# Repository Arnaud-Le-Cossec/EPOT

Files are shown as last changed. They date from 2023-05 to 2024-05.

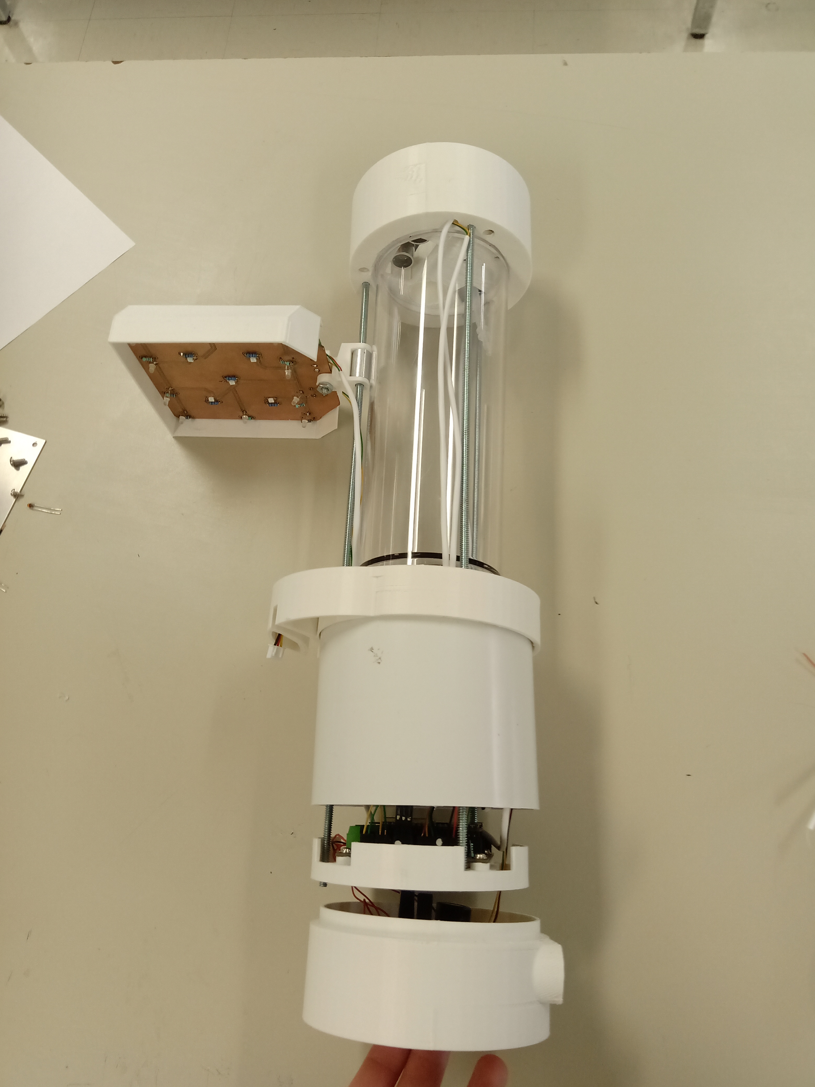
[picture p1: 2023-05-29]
Photo/EPOT_img3.jpg

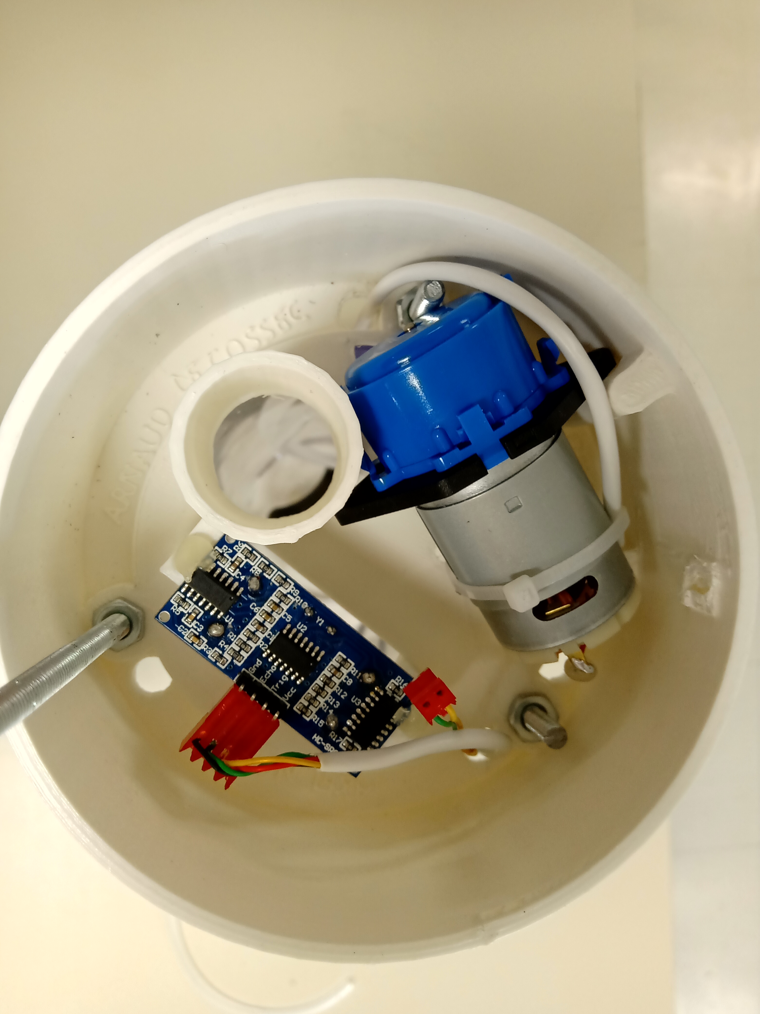
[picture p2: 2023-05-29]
Photo/EPOT_img5.jpg

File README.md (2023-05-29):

# PROJET EPOT

Réalisé par
Arnaud LE COSSEC
Axel NOUY

Session hiver 2023 - Collège Lionel Groulx

Qu'est-ce que EPOT ?

EPOT est un projet réalisé dans le cadre de la session hiver 2023 au collège Lionel Groulx. L'objectif du projet est de permettre à tout le monde faire pousser ses propres plantes chez soi sans avoir la main verte !

Il s'agit d'un pot de fleur intelligent et connecté, contrôlé par une application mobile. EPOT permet d'automatiser l'arrosage et l'éclairage d'une plante grâce à de nombreux capteurs : capteur d'humidité, de luminosité, de température et de niveau d'eau.

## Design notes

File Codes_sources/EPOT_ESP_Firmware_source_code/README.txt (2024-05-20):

READ ME
-------------Comment compiler ce projet ------------
1. ouvrir VScode.
2. Installer PlatformIO.
3. Dans "PlatformIO Home", créer un nouveau projet.
4. Entrer un nom de projet, sélectionner la carte [ESP32 Wrover DevKit] avec Arduino framework.
5. Copier le contenu de "main.cpp" dans le "main" du projet.
6. Copier le fichier "EPOT_lib.h" dans le dossier "src" du project.
7. Dans le fichier "platform.ini", changer ou ajouter les lignes suivantes :
	monitor_speed = 9600
	board_upload.flash_size = 8MB
	board_build.partitions = custom_partition.csv
Le fichier "platform.ini" doit désormais ressembler à celui fourni dans ce dossier
8. Dans la racine du projet, copier le fichier "custom_partition.csv".
9. Depuis "PlatformIO Home", cliquer sur "libraries" pour installer les librairies requises

Le fichier compilé en .elf et .bin est disponible dans le dossier "buid"
----------------- Notes -----------------------
Avant de compiler, il faut changer les paramètres de la base de données dans "EPOT_lib.h" :
#define DATABASE_API_KEY "entrez votre API de base de données"
#define DATABASE_URL "entrez votre URL de base de données" 
#define DATABASE_USER_EMAIL "user@email.com"
#define DATABASE_USER_PASSWORD "PASSWORD123"

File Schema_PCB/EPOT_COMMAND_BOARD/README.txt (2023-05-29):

README
Ce dossier contient l'archive du projet KiCAD du module de commande 
Fichier projet : EPOT_COMMAND_BOARD.kicad_pro
Schéma : EPOT_COMMAND_BOARD.kicad_sch
PCB : EPOT_COMMAND_BOARD.kicad_pcb
Paramètres : EPOT_COMMAND_BOARD.kicad_prl

Vous trouverez également une version .png du schéma ainsi qu'une note indiquant les modifications effectuées sur le circuit imprimé.

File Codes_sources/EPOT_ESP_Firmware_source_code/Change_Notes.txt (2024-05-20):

/*****************************************************
EPOT Project - ESP32 Firmware
(c)2023 Arnaud LE COSSEC
(c)2023 College Lionel Groulx
*****************************************************/

/*****************************************************
Change Notes : 
28/03/2023a : File creation
              void LED_init(void);
              void LED_set(uint8_t freq);
              void Ultrasonic_init(void);
              float Ultrasonic_Read(void);
              void Aref_init(void);
              void Temp_init(void);
              float Temp_Read(void);
              void Photo_Cell_init(void);
              float Photo_Cell_Read(void);
              void Humidity_init(void);
              float Humidity_Read(void);
29/03/2023a : POST test implementation
              LED not flashing bug fixed (prototype used instead of function call)
29/03/2023b : Task implementation
              Task Sensors Update
              Task Sensors Print - debug only, to be removed later on
29/03/2023c : Wifi setup implementation
29/03/2023d : Database setup implementation
              Code separation with EPOT_lib.h
31/03/2023a : watchdog implementation
03/04/2023a : Sensors to database
              Ledc library error fixed
04/04/2023a : Error log to database
              void Database_Self_test_repport(uint8_t Error_Count, uint8_t *Error_log)
              Change uint8_t Self_test(uint8_t *Error_log_table) : text as const char*
04/04/2023b : Bluetooth implementation
12/04/2023a : Startup sequence (stopped due to flash size issue)
13/04/2023a : New partion table with 3MB free for application use
13/04/2023b : Startup sequence (continuation)
              Task_database_read() / Task_database_write() deleted because replaced by task_database_update()
19/04/2023a : Database authentification refresh implementation
              [bug fix] "Invalid data; couldn't parse JSON object, array, or value." fixed : when left unconnected, 
              thermistor value was too large for the database. Temperature capped to 70°C
19/04/2023b : [bug fix] Bluetooth authentification systematic timeout fixed
20/04/2023a : [bug fix] Bluetooth authentification failed when retry
20/04/2023b : SSID and WIFI password exchange
27/04/2023a : Wifi connects from exchanged SSID and Password
27/04/2023b : Queue recieve moved to read sensors more often Task_Database_Update_routine
              Wifi connection timeout : if ESP can't connect to wifi, it restart credidentials exchange via Bluetooth
03/05/2023a : Permanent storage implementation with preferences.h library
              Push button reading implementation
03/05/2023b : Repace sensor queues for global variables to facilitate access for multiple tasks
03/05/2023c : Database commands and threshold levels reading
04/05/2023a : Automation - Force run/stop
              LED GPIO 17 and UV GPIO16 are not connected on VROVER-E. Replaced for GPIO 5 and 15 respectively
08/05/2023a : Database triggers
09/05/2023a : Update commands and levels from database triggers
09/05/2023b : Automation - Auto mode
10/05/2023a : Database sensor update only when sensor value changed
              if button pressed durring operation, hard reset is performed
15/05/2023a : RTOS Removed. RTOS handles memory in a weird way : random crashes due to memory allocation errors. 
15/05/2023b : Database update at startup
18/05/2023a : [BUG FIX] after 1h of runtime, firebase wants to refresh authentification tokens, but fails due to lack of memory
19/05/2023a : Delay added after firebase stream reconnection. Watchdog timeout extended to accomodate this delay.
20/05/2023a : LED to show CPU activity in the loop
22/05/2023a : Added relay output to cut 5v at startup
              Ultrasonic sensor measure overhaul
23/05/2023a : Pump automation overhaul
28/05/2023a : Commenting

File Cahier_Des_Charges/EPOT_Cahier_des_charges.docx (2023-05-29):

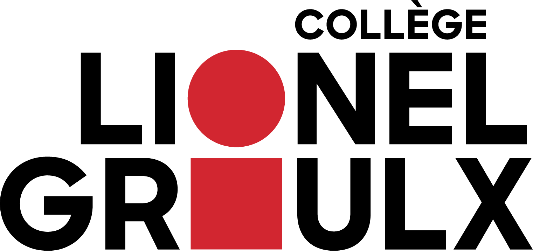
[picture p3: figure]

| | PROJET EPOT
| CAHIER DES CHARGES
Auteurs : Arnaud LE COSSEC Axel NOUY | Date : 27/05/23 | | Révision : v1.0 | Pages : 4

I – AVANT PROPOS

Le présent document revient sur les choix réalisés pour le projet EPOT. Nous reviendrons sur la constitution du cahier des charges puis sur la manière dont il a été mis en place.

II – CAHIER DES CHARGES

Le projet consiste en la création d'un pot de fleur intelligent et connecté, contrôlé par une application mobile. Il devra être capable d'arroser automatiquement les plantes à partir de la mesure de l'humidité du sol. L'éclairage devra lui aussi être contrôlé en fonction de la luminosité extérieure afin d'accomplir la consommation la plus faible possible. Il devra également être capable de mesurer et d'afficher la température dans l'air. L'alimentation devra être connectée au secteur et si possible sur batterie alimenter via un panneau solaire. Tous ces éléments devront être accessibles et contrôlables sur une application mobile. Celle-ci affichera les mesures des différents capteurs et laissera à l'utilisateur le choix d'une opération manuelle ou automatique de l'arrosage et de l'éclairage avec la possibilité de sélectionner des préréglages parmi les plantes proposées (niveau d'humidité, luminosité).

Le tableau ci-dessus récapitule ces exigences :

Fonctionnalités | Ce qui permet de mettre en œuvre ces fonctionnalités | Précision/ Résolution/ Contraintes
Arrosage automatique des plantes | → Capteur humidité du sol → Capteur niveau du réservoir → Électrovanne / Pompe / Brumisateur | Résolution de humidité au pourcentage près. Niveau d’eau au pourcentage près Arrosage lent et précisément contrôlable
Éclairage automatique | → Capteur luminosité ambiante → Lumière réglable (différentes intensités/couleur) → Consommation la plus faible possible | Capteur doit pouvoir traduire les différents niveaux de luminosités de la journée. Éclairage doit pouvoir être supporté par l’alimentation
Surveillance de l'atmosphère | → Capteur de température | Doit donner une idée de la température Résolution au dixième de degré Précision requise faible
Surveillance/gestion sur une application smartphone | → Afficher l'état des capteurs (température niveau d’eau, …) → Réglage sur différents modes (manuel, automatique, type de plante, …) L’utilisateur peut choisir lui-même les niveaux (manuel) ou choisi parmi des préréglages selon le type de plante → Communication des informations via Wi-Fi /Bluetooth | Temps de réaction le plus faible possible
Alimentation | → Si possible batterie et panneau solaire → Sinon sur secteur avec transformateur mural | Doit supporter une utilisation prolongée
Prototype | → Impression 3D | → Cacher les composants et les circuits imprimés → Prévoir des aérations

III – RÉALISATION DU CAHIER DES CHARGES

Cette partie revient les choix, difficultés et solutions trouvés au cours du projet pour mettre en œuvre le cahier des charges.

A) Microcontrôleur

Le module de commande a été construit autour du microcontrôleur ESP32. Le choix de ce microcontrôleur s'est fait sur la base de ses options de connectivités avec la prise en charge du Wi-Fi et du Bluetooth. Le module de commande a également été réalisé avec la protection des composants en tête : Des diodes et des résistances ont été placées à des positions stratégiques pour empêcher les courants inverses et limiter les effets de pic de tension. Les actionneurs (Pompe, LEDs) sont également isolés du microcontrôleur par des optocoupleurs.

Le firmware du microcontrôleur a pour rôle de récupérer les mesures des capteurs, d'effectuer les conversions nécessaires et de mettre à jour la base de données. Dans le même temps, il doit pouvoir récupérer les instructions de l'application mobile, elles aussi stockées dans la base de données, pour contrôler les actionneurs (Pompe et LEDs). Le Wi-Fi sera donc utilisé pour communiquer avec la base de données sur internet, tandis que le Bluetooth servira seulement pour la configuration du SSID et du mot de passe Wi-Fi.

Le temps de réactivité du microcontrôleur face aux changements dans la base de données est apparu pour comme un facteur important. Le programme demande donc à la base de données de l'avertir dès qu'il y a un changement, ce qui déclenche une interruption pour récupérer la donnée concernée. Le résultat est un délai maximum de 3 secondes entre la commande sur l'application et la réception de cette commande sur le microcontrôleur. La mise à jour des capteurs, quant à elle est moins critique et n'est effectué que toutes les 5 secondes pour économiser de la bande passante.

B) Application mobile

Pour l'application, nous avons décidé de ne pas utiliser MIT APP Inventor, car malgré sa simplicité d'utilisation, il nous semblait que nous ne pourrions jamais faire ce que nous voulions. Nous avons donc effectué des recherches et nous avons décidé de coder l'application sur L'IDE Android studio qui est spécialisé dans la conception d'application pour Android. Pour ce qui est du langage l'application est codée en Kotlin, le langage de programmation préconisé par Google.

L'application dans sa forme actuelle permet :

- À l’utilisateur de choisir la plante qu'il veut utiliser avec des préréglages sur les niveaux d’humidité et d’éclairage désiré.

- De créer soi-même sa fiche de plante s’il ne trouve pas sa plante

- De mettre toutes les informations relatives aux plantes de l’utilisateur sur une base de données afin de pouvoir y accéder de n'importe où.

- D’afficher les valeurs de tous les capteurs de la manière la plus graphique possible

- De choisir entre un mode automatique et un mode manuel pour l'arrosage et pour l'éclairage

- De choisir l'intensité de l'éclairage pour chaque type de LED indépendamment
- De communiquer en Bluetooth avec l’ESP32 afin de paramétrer le SSID et le mot de passe du Wi-Fi

C) Arrosage des plantes

Nous avons choisi pour l'arrosage de la plante d'utiliser une pompe péristaltique, car elle nous permet de contrôler de manière très précise la quantité d'eau déversée (goutte-à-goutte). Nous avions également testé la possibilité d'utiliser une autre pompe 3VDC, mais le débit était trop élevé pour notre utilisation. Nous faisons fonctionner cette pompe en 5VDC sur les 12V nominaux pour nous permettre de ralentir encore le débit et de l'alimenter avec la même sortie que les LED.

Pour le capteur d'humidité, nous avons choisi un capteur capacitif de chez Adafruit. Ce choix a été dirigé par sa simplicité d'utilisation et sa disponibilité. Un autre facteur intervenant dans le choix de ce capteur est la présence d'un solder mask sur les électrodes qui les protège de la corrosion, contrairement à d'autres capteurs résistifs où elles sont exposées.

Pour pouvoir surveiller le niveau d'eau dans le réservoir, nous avons opté pour un capteur de distance à ultrason. Ce capteur, facilement disponible, est aussi utilisé fréquemment pour la mesure des niveaux dans des cuves. Avec la distance mesurée, nous pouvons facilement effectuer la conversion en pourcentage pour obtenir le niveau d'eau de notre réservoir. Nous avons rencontré quelques difficultés avec ce capteur au cours des différents tests que nous avons effectués. Les parois étroites du réservoir sont propices à l'écho des ondes ultrason. Une mesure effectuée pouvait donc varier fortement avec la précédente. Pour pallier ces erreurs nous avons décidé d'effectuer deux mesures et de ne prendre leur résultat que si elle était identique. Cette méthode est possible, car le niveau d'eau n'évolue pas rapidement.

D) Éclairage

Pour la gestion de l'éclairage nous avons choisi de partir sur 2 types de LED : des LEDs blanches couvrant tout le spectre visuel et des LEDs UV étant donné que certaines plantes en ont besoin pour pousser, mais également si certaines plantes ne sont pas exposées au UV lorsqu'elles sont jeunes elles ne pourront pas être replantées dehors, car elles ne seront pas capables de survivre aux rayons UV du soleil. Elles seront alimentées en 5V car les, LED blanche ont une chute de tension de 3.2V ce qui rend leur alimentation en 3.3V très complexe.

Pour le capteur de luminosité ambiante, nous avions d'abord porté notre choix sur un phototransistor, car nous l'avions déjà utilisé sur un autre projet. Cependant, nous nous sommes vite rendu compte que si nous voulions mesurer une intensité lumineuse et non pas un seuil. Le phototransistor n'était pas le meilleur choix. Nous nous sommes alors tournés vers une photorésistance qui permet de mesurer elle l'intensité lumineuse. Cette dernière nous permettra de décider si oui ou non, il faut éteindre la lumière l'éclairage.

E) Surveillance de la température

Pour la mesure de température, nous nous sommes orientés vers une thermistance CTN (à coefficient négatif). Ce choix a été guidé par notre expérience avec un tel capteur ainsi que pour son coût très faible. Grâce à ce composant, nous pouvons mesurer la température et l'afficher sur notre application. Cependant, nous nous sommes par la suite rendu compte de la faible linéarité du convertisseur analogique-numérique de l'ESP32, résultant en une mesure de températures peu précise. Nous avons dans le code appliqué une correction fixe, mais dans le futur, nous pourrions utiliser un capteur numérique tel que le BMP390.

F) Alimentation

Pour l'alimentation, nous avons choisi de partir sur une alimentation linéaire, car nous avons déjà étudié son fonctionnement auparavant. La faible consommation totale soutient ce choix avec une quantité limité d'énergie à dissiper. Nous avions besoin d'une sortie 5V (LEDs, pompe et capteur ultrason) ainsi que d'une sortie 3.3V (ESP32, autres capteurs). Nous avons donc choisi d'utiliser 2 régulateurs 5V et un régulateur 3.3V (voir PCB alimentation). Après avoir testé notre PCB nous avons remarqué que les régulateurs 5V ne partageaient pas réellement la charge et qu’un des deux régulateurs chauffait bien plus que l'autre. Nous avons donc décidé de séparer la sortie des deux régulateurs 5V, une pour l'alimentation des LEDs et du capteur ultrason et une pour l'alimentation de la pompe. Si nous devions refaire le projet, nous changerions cette alimentation linéaire pour une alimentation à découpage qui est bien plus efficace et qui permet de tirer beaucoup plus de courant en dissipant moins de chaleur.

G) Prototype

Enfin en ce qui concerne notre prototype nous voulions avoir une conception simple et efficace. Nous avons donc décidé de réaliser nos pièces en impression 3D. Cela nous permet de concevoir sur mesure nos pièces afin de servir parfaitement nos besoins. Le choix du matériau s’est porté sur du PLA, à base d’amidon de maïs biodégradable, participant à une démarche écoresponsable.

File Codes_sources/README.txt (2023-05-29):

"EPOT_APP_APK" contient les executables android de l'application mobile
"EPOT_APP" contient le ficher source l'application mobile sur android studio
"EPOT_ESP_Firmware_source_code" contient les fichiers sources du firmware de l'application

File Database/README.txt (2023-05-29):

Ce dossier contient l'archive .jason de la base de donnée Firebase servant au système EPOT. Il est possible de la réimporter dans Firebase.

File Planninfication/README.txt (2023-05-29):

Ce dossier contient les fichiers ayant servi à la planification du projet.
Le fichier .Mpp est un fichier MS projet.

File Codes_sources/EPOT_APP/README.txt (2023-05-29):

Pour ouvrir les fichiers de l'application il faut installer l'ide android Studio avec le sdk android 9.0 revision 28 

Il se peut qu'un fichier soit rempli d'erreur, pour palier à ce souci il suffit de copier le contenu du fichier puis le supprimer et le recrée avec le même nom et la même extension (kotlin class file->class)

Pour tout problème n'hésiter pas à me contacter

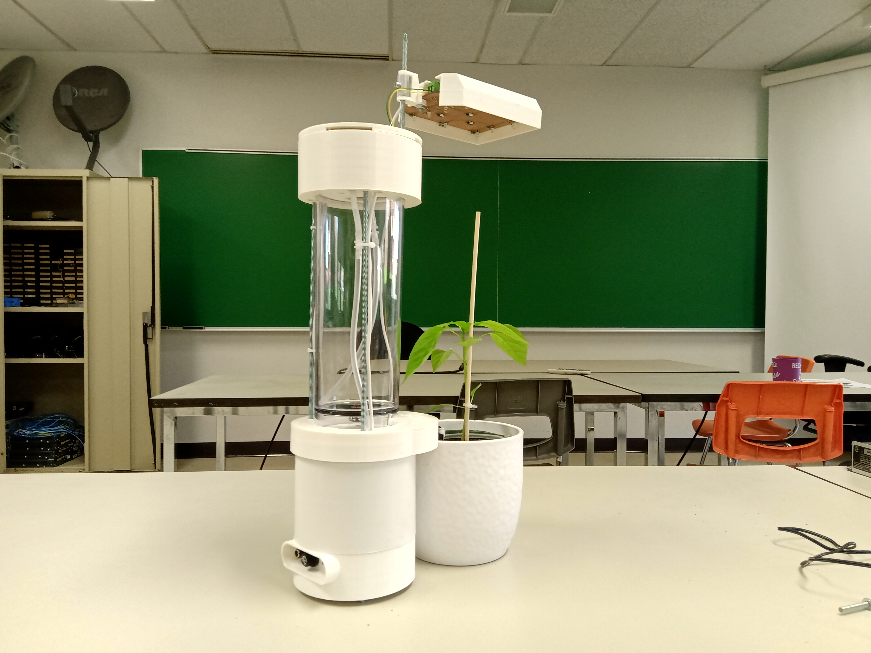
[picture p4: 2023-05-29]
Photo/EPOT_img7.jpg

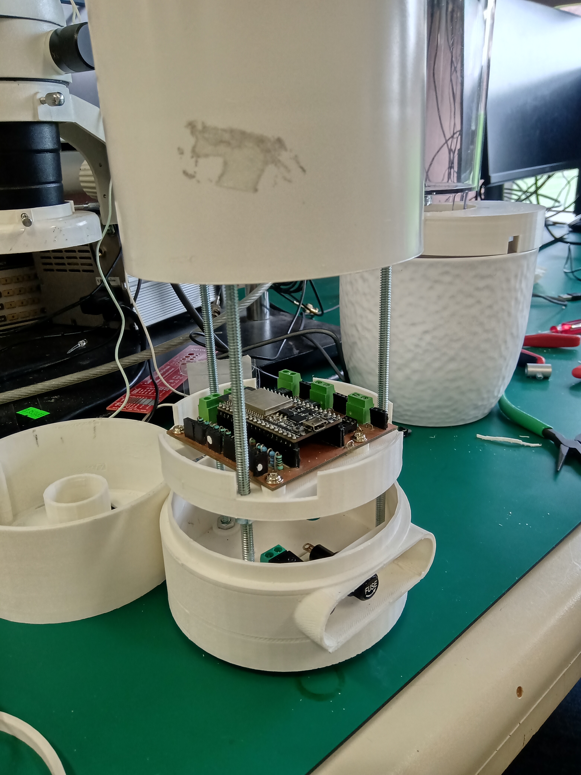
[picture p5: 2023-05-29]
Photo/EPOT_img1.jpg

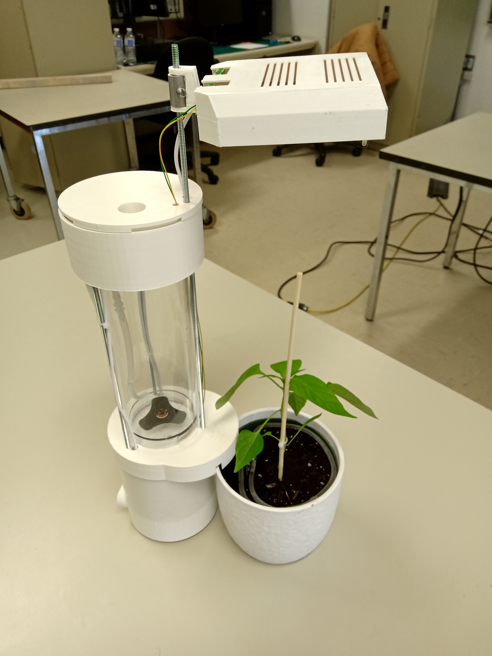
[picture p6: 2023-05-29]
Photo/EPOT_img6.jpg

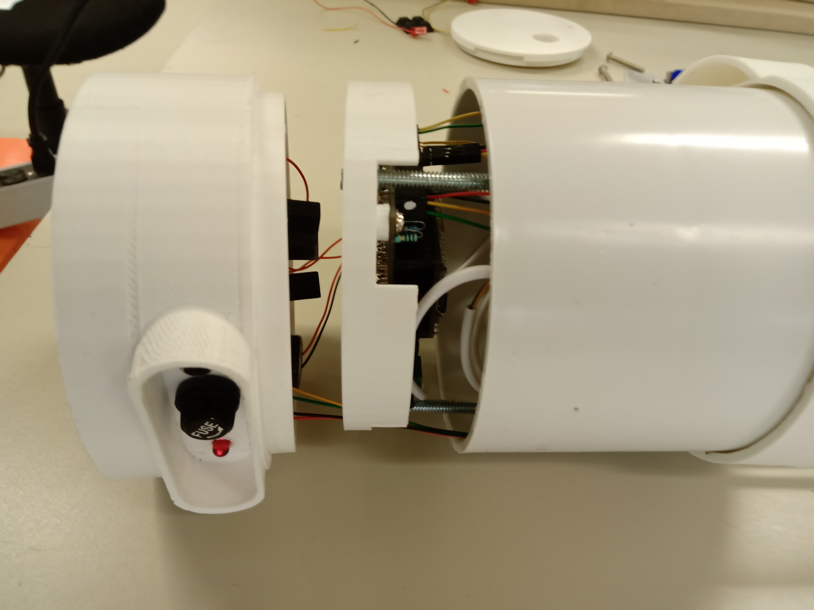
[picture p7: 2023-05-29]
Photo/EPOT_img4.jpg

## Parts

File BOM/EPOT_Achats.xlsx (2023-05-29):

Index | Nom / Desciption | Part N° | Fournisseur | N° de fournisseur | Lien | Prix unitaire | Quantité | Prix (CAD) | Datasheet | Note | Acheté par
 | Microcontrôleur
1 | ESP32 | ESP32-DEVKITC-VE | Digikey | 1965-ESP32-DEVKITC-VE-ND | https://www.digikey.ca/en/products/detail/espressif-systems/ESP32-DEVKITC-VE/12091812 | 16.88 | 1 | 16.88 | https://www.espressif.com/en/support/documents/technical-documents | MC | Cégep
 | Actionneurs
2 | SUBMERSIBLE 3VDC VERTICAL PUMP | 4547 | Digikey | 1528-4547-ND | https://www.digikey.ca/en/products/detail/adafruit-industries-llc/4547/11627730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 | 4.53 | 1 | 4.53 | 3VDC; 0.12A; 0.36W | Non utilisé | Cégep
2 | Pompe péristaltique 12 VCC | - | Amazon | - | https://www.amazon.ca/-/fr/Kamoer-p%C3%A9ristaltique-aquarium-laboratoire-analytique/dp/B07GWJ78FN | 12 | 1 | 12 | 12VDC; 0.25A |  | Cégep
3 | Ultraviolet (UV) Emitter | T1691UV--20C000212U1930 | Digikey | 3147-T1691UV--20C000212U1930CT-ND | https://www.digikey.ca/en/products/detail/harvatek-corporation/T1691UV-20C000212U1930/17289605 | 0.43 | 5 | 2.15 | https://media.digikey.com/pdf/Data%20Sheets/Harvatek%20PDFs/T1691UV--20C000212U1930.pdf | ML | Cégep
4 | LED WHITE DIFFUSED T-1 T/H | QBL7IW60D-WW | Digikey | 1516-QBL7IW60D-WW-ND | https://www.digikey.ca/en/products/detail/qt-brightek-qtb/QBL7IW60D-WW/10441171 | 0.61 | 10 | 6.1 | https://www.qt-brightek.com/datasheet/QBL7IW60D-XX.pdf | ML | Cégep
 | Capteurs
5 | THERMISTOR NTC 10KOHM 3977K BEAD | NTCLE100E3103JB0 | Digikey | BC2301-ND | https://www.digikey.ca/en/products/detail/vishay-beyschlag-draloric-bc-components/NTCLE100E3103JB0/769411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 | 1.24 | 2 | 2.48 | https://www.vishay.com/docs/29049/ntcle100.pdf |  | Cégep
6 | PHOTO CELL (CDS PHOTORESISTOR) - Adafruit Industries LLC | 161 | Digikey | 1528-2141-ND | https://www.digikey.ca/en/products/detail/adafruit-industries-llc/161/7244927 | 1.46 | 2 | 2.92 | https://cdn-learn.adafruit.com/downloads/pdf/photocells.pdf |  | Cégep
7 | PHOTOTRANSISTOR 900 TO 980 NM | BPV11F | Digikey | 751-1004-ND | https://www.digikey.ca/en/products/detail/vishay-semiconductor-opto-division/BPV11F/1681138 | 1.69 | 2 | 3.38 | https://www.vishay.com/docs/81505/bpv11f.pdf | Non utilisé | Cégep
7 | Capteur humidité x2 | Gikfun EK1940 | Amazon | - | https://www.amazon.ca/EK1940-dhumidit%C3%A9-capacitifs-r%C3%A9sistants-corrosion/dp/B07H3P1NRM | 10.51 | 1 | 10.51 | - |  | Cégep
8 | ULTRASONIC DISTANCE SENSOR - HC- | SEN-15569 | Digikey | 1568-SEN-15569-ND | https://www.digikey.ca/en/products/detail/sparkfun-electronics/SEN-15569/10384560?productid=10384560 | 6.9 | 1 | 6.9 | https://cdn.sparkfun.com/datasheets/Sensors/Proximity/HCSR04.pdf |  | Cégep
 | Circuits intégrés
9 | IC REG LINEAR 3.3V 500MA TO220-3 | TLV2217-33KCSE3 | Digikey | 296-21611-5-ND | https://www.digikey.ca/en/products/detail/texas-instruments/TLV2217-33KCSE3/1494004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 | 2.47 | 2 | 4.94 | https://www.ti.com/lit/ds/slvs067m/slvs067m.pdf | MA | Cégep
10 | IC REG LINEAR 5V 1.5A TO220AB | L7805CV | Digikey | 497-1443-5-ND | https://www.digikey.ca/en/products/detail/stmicroelectronics/L7805CV/585964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 | 1.06 | 3 | 3.18 | https://www.st.com/content/ccc/resource/technical/document/datasheet/41/4f/b3/b0/12/d4/47/88/CD00000444.pdf/files/CD00000444.pdf/jcr:content/translations/en.C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 | MA | Cégep
11 | MOSFET N-CH 60V 37.2A TO220AB | DMT6009LCT | Digikey | DMT6009LCTDI-5-ND | https://www.digikey.ca/en/products/detail/diodes-incorporated/DMT6009LCT/6051857 | 1.44 | 4 | 5.76 | https://www.diodes.com/assets/Datasheets/DMT6009LCT.pdf | MC | Cégep
12 | Optocoupleur 4N25 | - | Magazin Cégep | - | - | 0 | 3 | 0 | https://www.vishay.com/docs/83725/4n25.pdf | MC | Cégep
 | Autes composanrs passifs / actifs
13 | Résistance axiale 1/4W 100Ω | - | Libre-accès Cégep | - | - | 0 | 5 | 0 |  | MC | Cégep
14 | Résistance axiale 1/4W 1kΩ | - | Libre-accès Cégep | - | - | 0 | 7 | 0 |  | MA; MC | Cégep
15 | Résistance axiale 1/4W 3.7kΩ | - | Libre-accès Cégep | - | - | 0 | 1 | 0 |  | MC | Cégep
16 | Résistance axiale 1/4W 10kΩ | - | Libre-accès Cégep | - | - | 0 | 7 | 0 |  | MC | Cégep
17 | Condensateur ALUM 1000UF 20% 35V RADIAL | - | Digikey | P10387TB-ND | https://www.digikey.ca/en/products/detail/panasonic-electronic-components/ECA-1VM102B/268472 | 0.63 | 2 | 1.26 | - | MA | Cégep
18 | Condensateur céramique 0.1uF | - | Libre-accès Cégep | - | - | 0 | 5 | 0 |  | MA; MC | Cégep
19 | Condensateur céramique 0.33uF | - | Libre-accès Cégep | - | - | 0 | 2 | 0 |  | MA | Cégep
20 | Condensateur céramique 22uF | - | Libre-accès Cégep | - | - | 0 | 1 | 0 |  | MA | Cégep
21 | BRIDGE RECT 1PHASE 600V 2A KBP | KBP206G | Digikey | KBP206GDI-ND | https://www.digikey.ca/en/products/detail/diodes-incorporated/KBP206G/278624 | 0.82 | 1 | 0.82 | https://www.diodes.com/assets/Datasheets/ds21205.pdf | MA | Cégep
22 | Diode ZENER 6.2V 1W DO41 | 1N4735A-T50A | Digikey | 488-1N4735A-T50ACT-ND | https://www.digikey.ca/en/products/detail/onsemi/1N4735A-T50A/977223 | 0.43 | 1 | 0.43 | https://rocelec.widen.net/view/pdf/7qfz7dzkx8/ONSM-S-A0003585147-1.pdf?t.download=true&u=5oefqw | MA | Cégep
23 | Diode ZENER 3.9V 1W DO41 | 1N4730A TR | Digikey | 1N4730ACSCT-ND | https://www.digikey.ca/en/products/detail/central-semiconductor-corp/1N4730A-TR/5212199 | 0.42 | 1 | 0.42 | https://my.centralsemi.com/datasheets/1N4728A-4764A.PDF | MA | Cégep
24 | Diode axiale 0.7v max - 300mA average | - | Libre-accès Cégep | - | - | 0 | 7 | 0 |  | MC | Cégep
25 | LED générique | - | Libre-accès Cégep | - | - | 0 | 3 | 0 |  | MA; MC | Cégep
26 | Relai 5v REEP SIP | - | Madd électronique | - | - | 2.75 | 1 | 2.75 |  |  | Fonds perso
14 | FUSE CERAMIC 5A 250VAC 5X20MM | 0659C5000-12 | Digikey | 507-2009-ND | https://www.digikey.ca/en/products/detail/bel-fuse-inc/0659C5000-12/5843993 | 0.61 | 2 | 1.22 | - |  | Cégep
27 | Transformateur 8VDC | - | Récupération | - | - | 0 | 1 | 0 |  |  | Cégep
16 | AC/AC WALL MNT ADAPTER 12V 2A | WAU12-2000 | Digikey | 237-1881-ND | https://www.digikey.ca/en/products/detail/triad-magnetics/WAU12-2000/4915295 | 26.15 | 1 | 26.15 | - | Non utilisé | Cégep
 | Connecteurs
28 | TERM BLK 2POS SIDE ENTRY 5MM PCB | 691137710002 | Digikey | 732-10955-ND | https://www.digikey.ca/en/products/detail/w%C3%BCrth-elektronik/691137710002/6644051 | 0.59 | 10 | 5.9 | https://www.we-online.com/components/products/datasheet/691137710002.pdf | MA; MC; ML | Cégep
29 | DC POWER JACK | - | Madd électronique | 1939-G-1005B-ND | https://www.digikey.ca/en/products/detail/globtek-inc/G-1005B/16515799 | 1.75 | 1 | 1.75 | https://www.globtek.com/pdf/manual-datasheets/G-1005B.pdf |  | Fonds perso
30 | Header femmelle | - | Magazin Cégep | - | - | 0 | 27 pins | 0 |  | MC | Cégep
15 | FUSE BLOCK CART 250V 6.3A PCB | 64700001003 | Digikey | F4544-ND | https://www.digikey.ca/en/products/detail/littelfuse-inc/64700001003/468211?s=N4IgTCBcDaIGIBYCsCEFoByAREBdAvkA | 1.24 | 1 | 1.24 | https://www.littelfuse.com/media?itemid=58dc6e54-1db0-4475-b4fb-5f91c9d24e4c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 |  | Cégep
19 | DC POWER JACK,2.5MM;PCB MOUNT | G-1005B | Digikey | 1939-G-1005B-ND | https://www.digikey.ca/en/products/detail/globtek-inc/G-1005B/16515799 | 0.82 | 1 | 0.82 | https://www.globtek.com/pdf/manual-datasheets/G-1005B.pdf |  | Cégep
 | Mécanique
31 | POLYMAKER POLYTERRA PLA FILAMENT | RM-PL0322 | Digikey | 1942-RM-PL0322-ND | https://www.digikey.ca/en/products/detail/lulzbot/RM-PL0322/16186585 | 30.65 | 1 | 30.65 | https://cdn.shopify.com/s/files/1/0548/7299/7945/files/PolyTerra_PLA_TDS_V5.1.pdf |  | Cégep
32 | Tiges filetés 10-24 36po | - | Rona | - | - | 2.79 | 2 | 5.58 |  |  | Fonds perso
33 | Ecrous (boite de 100) | - | Rona | - | - | 7.99 | 1 | 7.99 |  |  | Fonds perso
34 | Tube en PVC | - |  | - | - | 10 | 1 | 10 |  |  | Fonds perso
35 | Tuyau 5mm x 3mm - 1m de longueur | - | Amazon.ca | - | https://www.amazon.ca/-/fr/silicone-souple-transparent-diam%C3%A8tre-int%C3%A9rieur/dp/B08GP6F2QZ | 9.99 | 1 | 9.99 |  |  | Fonds perso
36 | Réservoir de caftère | - | Récupération | - | - | 0 | 1 | 0 |  |  | Cégep
 | Plantes
37 | Tomate Orange Hat – Bio | - | Jardins de l'écoumène | - | https://www.ecoumene.com/produit/semences/potageres/tomate/type-cerise/tomate-orange-hat-bio/ | 4.19 | 1 | 4.19 | - |  | Cégep
 |  |  |  |  | TOTAL (CAD) |  |  | 192.89
 | Notations :
 | MA | Module d'alimentation
 | MC | Module de commande
 | ML | Module lumière

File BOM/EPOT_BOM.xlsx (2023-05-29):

Index | Nom / Desciption | Part N° | Fournisseur | N° de fournisseur | Lien | Prix unitaire | Quantité | Prix (CAD) | Datasheet | Note
 | Microcontrôleur
1 | ESP32 | ESP32-DEVKITC-VE | Digikey | 1965-ESP32-DEVKITC-VE-ND | https://www.digikey.ca/en/products/detail/espressif-systems/ESP32-DEVKITC-VE/12091812 | 16.88 | 1 | 16.88 | https://www.espressif.com/en/support/documents/technical-documents | MC
 | Actionneurs
2 | Pompe péristaltique 12 VCC | - | Amazon | - | https://www.amazon.ca/-/fr/Kamoer-p%C3%A9ristaltique-aquarium-laboratoire-analytique/dp/B07GWJ78FN | 12 | 1 | 12 | 12VDC; 0.25A
3 | Ultraviolet (UV) Emitter | T1691UV--20C000212U1930 | Digikey | 3147-T1691UV--20C000212U1930CT-ND | https://www.digikey.ca/en/products/detail/harvatek-corporation/T1691UV-20C000212U1930/17289605 | 0.43 | 5 | 2.15 | https://media.digikey.com/pdf/Data%20Sheets/Harvatek%20PDFs/T1691UV--20C000212U1930.pdf | ML
4 | LED WHITE DIFFUSED T-1 T/H | QBL7IW60D-WW | Digikey | 1516-QBL7IW60D-WW-ND | https://www.digikey.ca/en/products/detail/qt-brightek-qtb/QBL7IW60D-WW/10441171 | 0.61 | 10 | 6.1 | https://www.qt-brightek.com/datasheet/QBL7IW60D-XX.pdf | ML
 | Capteurs
5 | THERMISTOR NTC 10KOHM 3977K BEAD | NTCLE100E3103JB0 | Digikey | BC2301-ND | https://www.digikey.ca/en/products/detail/vishay-beyschlag-draloric-bc-components/NTCLE100E3103JB0/769411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 | 1.24 | 2 | 2.48 | https://www.vishay.com/docs/29049/ntcle100.pdf
6 | PHOTO CELL (CDS PHOTORESISTOR) - Adafruit Industries LLC | 161 | Digikey | 1528-2141-ND | https://www.digikey.ca/en/products/detail/adafruit-industries-llc/161/7244927 | 1.46 | 1 | 1.46 | https://cdn-learn.adafruit.com/downloads/pdf/photocells.pdf
7 | Capteur humidité x2 | Gikfun EK1940 | Amazon | - | https://www.amazon.ca/EK1940-dhumidit%C3%A9-capacitifs-r%C3%A9sistants-corrosion/dp/B07H3P1NRM | 10.51 | 1 | 10.51 | -
8 | ULTRASONIC DISTANCE SENSOR - HC- | SEN-15569 | Digikey | 1568-SEN-15569-ND | https://www.digikey.ca/en/products/detail/sparkfun-electronics/SEN-15569/10384560?productid=10384560 | 6.9 | 1 | 6.9 | https://cdn.sparkfun.com/datasheets/Sensors/Proximity/HCSR04.pdf
 | Circuits intégrés
9 | IC REG LINEAR 3.3V 500MA TO220-3 | TLV2217-33KCSE3 | Digikey | 296-21611-5-ND | https://www.digikey.ca/en/products/detail/texas-instruments/TLV2217-33KCSE3/1494004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 | 2.47 | 1 | 2.47 | https://www.ti.com/lit/ds/slvs067m/slvs067m.pdf | MA
10 | IC REG LINEAR 5V 1.5A TO220AB | L7805CV | Digikey | 497-1443-5-ND | https://www.digikey.ca/en/products/detail/stmicroelectronics/L7805CV/585964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 | 1.06 | 2 | 2.12 | https://www.st.com/content/ccc/resource/technical/document/datasheet/41/4f/b3/b0/12/d4/47/88/CD00000444.pdf/files/CD00000444.pdf/jcr:content/translations/en.C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 | MA
11 | MOSFET N-CH 60V 37.2A TO220AB | DMT6009LCT | Digikey | DMT6009LCTDI-5-ND | https://www.digikey.ca/en/products/detail/diodes-incorporated/DMT6009LCT/6051857 | 1.44 | 3 | 4.32 | https://www.diodes.com/assets/Datasheets/DMT6009LCT.pdf | MC
12 | Optocoupleur 4N25 |  | Magazin Cégep | - |  | 0 | 3 | 0 | https://www.vishay.com/docs/83725/4n25.pdf | MC
 | Autes composanrs passifs / actifs
13 | Résistance axiale 1/4W 100Ω | - | Libre-accès Cégep | - | - | 0 | 5 | 0 |  | MC
14 | Résistance axiale 1/4W 1kΩ | - | Libre-accès Cégep | - | - | 0 | 7 | 0 |  | MA; MC
15 | Résistance axiale 1/4W 3.7kΩ | - | Libre-accès Cégep | - | - | 0 | 1 | 0 |  | MC
16 | Résistance axiale 1/4W 10kΩ | - | Libre-accès Cégep | - | - | 0 | 7 | 0 |  | MC
17 | Condensateur ALUM 1000UF 20% 35V RADIAL | - | Digikey | P10387TB-ND | https://www.digikey.ca/en/products/detail/panasonic-electronic-components/ECA-1VM102B/268472 | 0.63 | 2 | 1.26 | - | MA
18 | Condensateur céramique 0.1uF | - | Libre-accès Cégep | - | - | 0 | 5 | 0 |  | MA; MC
19 | Condensateur céramique 0.33uF | - | Libre-accès Cégep | - | - | 0 | 2 | 0 |  | MA
20 | Condensateur céramique 22uF | - | Libre-accès Cégep | - | - | 0 | 1 | 0 |  | MA
21 | BRIDGE RECT 1PHASE 600V 2A KBP | KBP206G | Digikey | KBP206GDI-ND | https://www.digikey.ca/en/products/detail/diodes-incorporated/KBP206G/278624 | 0.82 | 1 | 0.82 | https://www.diodes.com/assets/Datasheets/ds21205.pdf | MA
22 | Diode ZENER 6.2V 1W DO41 | 1N4735A-T50A | Digikey | 488-1N4735A-T50ACT-ND | https://www.digikey.ca/en/products/detail/onsemi/1N4735A-T50A/977223 | 0.43 | 1 | 0.43 | https://rocelec.widen.net/view/pdf/7qfz7dzkx8/ONSM-S-A0003585147-1.pdf?t.download=true&u=5oefqw | MA
23 | Diode ZENER 3.9V 1W DO41 | 1N4730A TR | Digikey | 1N4730ACSCT-ND | https://www.digikey.ca/en/products/detail/central-semiconductor-corp/1N4730A-TR/5212199 | 0.42 | 1 | 0.42 | https://my.centralsemi.com/datasheets/1N4728A-4764A.PDF | MA
24 | Diode axiale 0.7v max - 300mA average | - | Libre-accès Cégep | - | - | 0 | 7 | 0 |  | MC
25 | LED générique | - | Libre-accès Cégep | - | - | 0 | 3 | 0 |  | MA; MC
26 | Relai 5v REEP SIP | - | Madd électronique | - | - | 2.75 | 1 | 2.75
27 | Transformateur 8VDC | - | Récupération | - | - | 0 | 1 | 0
 | Connecteurs
28 | TERM BLK 2POS SIDE ENTRY 5MM PCB | 691137710002 | Digikey | 732-10955-ND | https://www.digikey.ca/en/products/detail/w%C3%BCrth-elektronik/691137710002/6644051 | 0.59 | 10 | 5.9 | https://www.we-online.com/components/products/datasheet/691137710002.pdf | MA; MC; ML
29 | DC POWER JACK | - | Madd électronique | 1939-G-1005B-ND | https://www.digikey.ca/en/products/detail/globtek-inc/G-1005B/16515799 | 1.75 | 1 | 1.75 | https://www.globtek.com/pdf/manual-datasheets/G-1005B.pdf
30 | Header femmelle | - | Magazin Cégep | - | - | 0 | 27 pins | 0 |  | MC
 | Mécanique
31 | POLYMAKER POLYTERRA PLA FILAMENT | RM-PL0322 | Digikey | 1942-RM-PL0322-ND | https://www.digikey.ca/en/products/detail/lulzbot/RM-PL0322/16186585 | 30.65 | 1 | 30.65 | https://cdn.shopify.com/s/files/1/0548/7299/7945/files/PolyTerra_PLA_TDS_V5.1.pdf
32 | Tiges filetés 10-24 | - | Rona | - | - | 2.79 | 2 | 5.58
33 | Ecrous (boite de 100 à $7.99) | - | Rona | - | - | 0.0799 | 12 | 0.9588
34 | Tube en PVC | - |  | - | - | 10 | 1 | 10
35 | Tuyau 5mm x 3mm - 1m de longueur | - | Amazon.ca | - | https://www.amazon.ca/-/fr/silicone-souple-transparent-diam%C3%A8tre-int%C3%A9rieur/dp/B08GP6F2QZ | 9.99 | 1 | 9.99
36 | Réservoir de caftère | - | Récupération | - | - | 0 | 1 | 0
 | Plantes
37 | Tomate Orange Hat – Bio | - | Jardins de l'écoumène | - | https://www.ecoumene.com/produit/semences/potageres/tomate/type-cerise/tomate-orange-hat-bio/ | 4.19 | 1 | 4.19 | -
 | Notations : |  |  |  | TOTAL (CAD) |  |  | 142.0888
 | MA | Module d'alimentation |  |  | Ce document ne prend en compte que les composants ayant servit au prototype final.
 | MC | Module de commande
 | ML | Module lumière

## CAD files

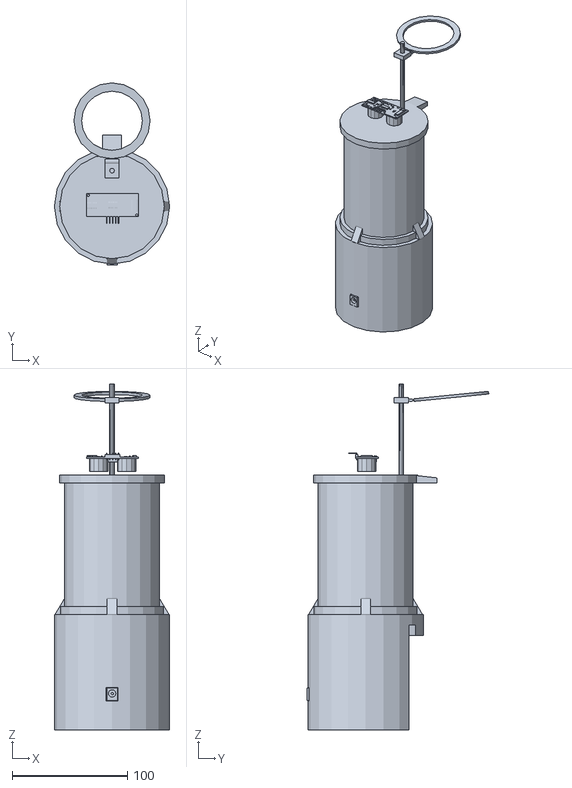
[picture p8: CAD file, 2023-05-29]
Mechanique/EPOT_premier_prototype.stl
100.0 x 158.0 x 300.0

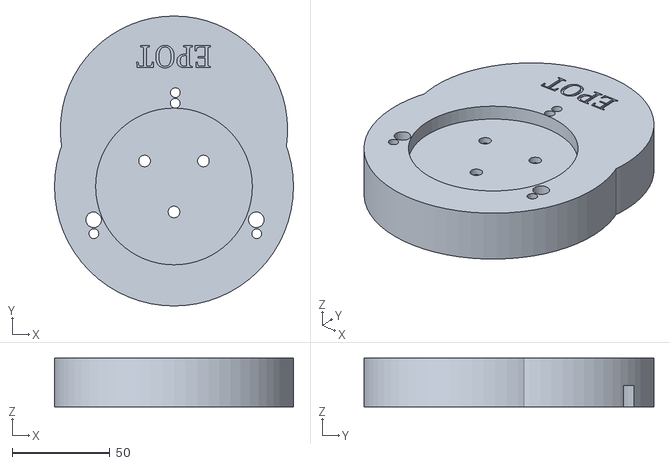
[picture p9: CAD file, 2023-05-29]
Mechanique/EPOT_TANK_BASE.stl
122.0 x 148.0 x 25.0

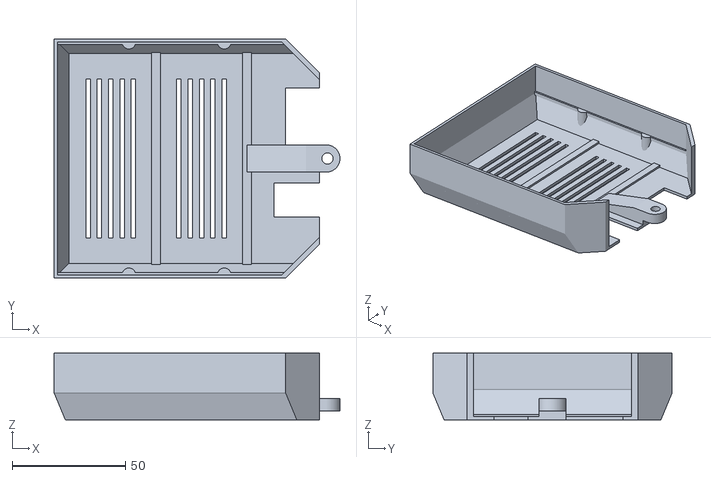
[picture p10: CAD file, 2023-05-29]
Mechanique/EPOT_LED_COVER.stl
126.0 x 105.5 x 29.5

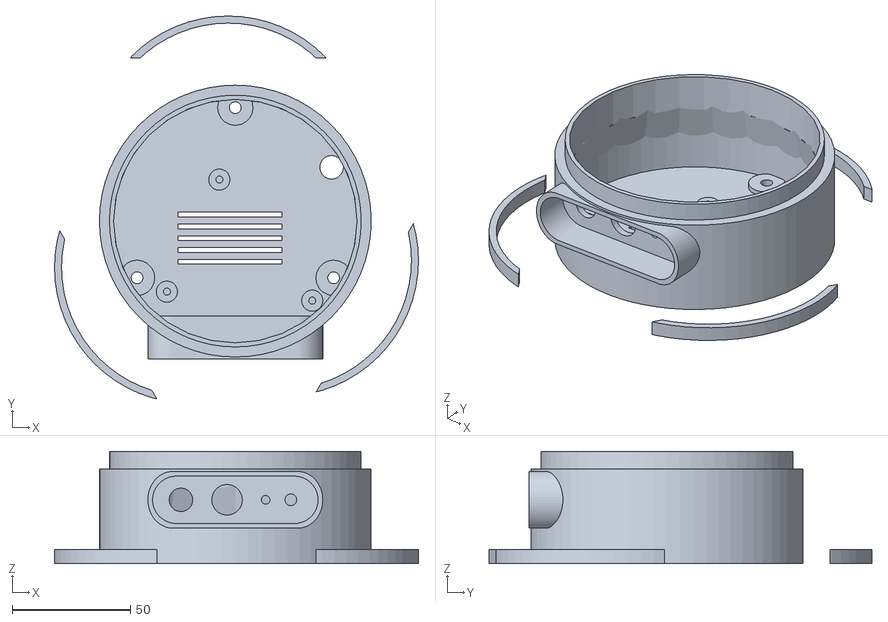
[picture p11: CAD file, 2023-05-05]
Mechanique/EPOT_BAS.stl
154.0 x 162.0 x 47.5

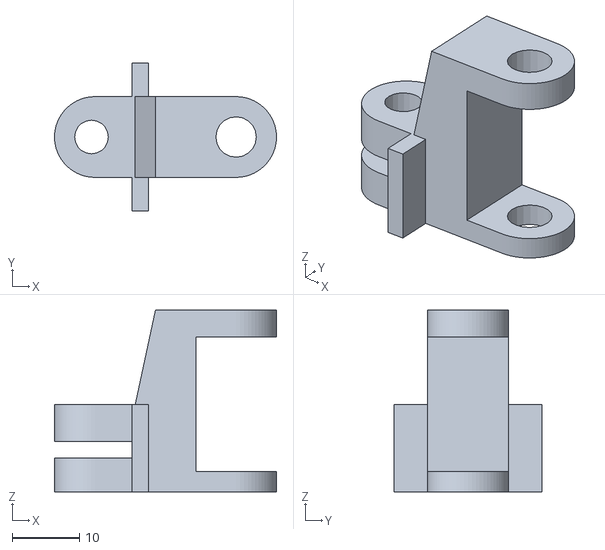
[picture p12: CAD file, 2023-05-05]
Mechanique/EPOT_LED_MODULE_ATTACHMENT.stl
33.0 x 22.0 x 27.0

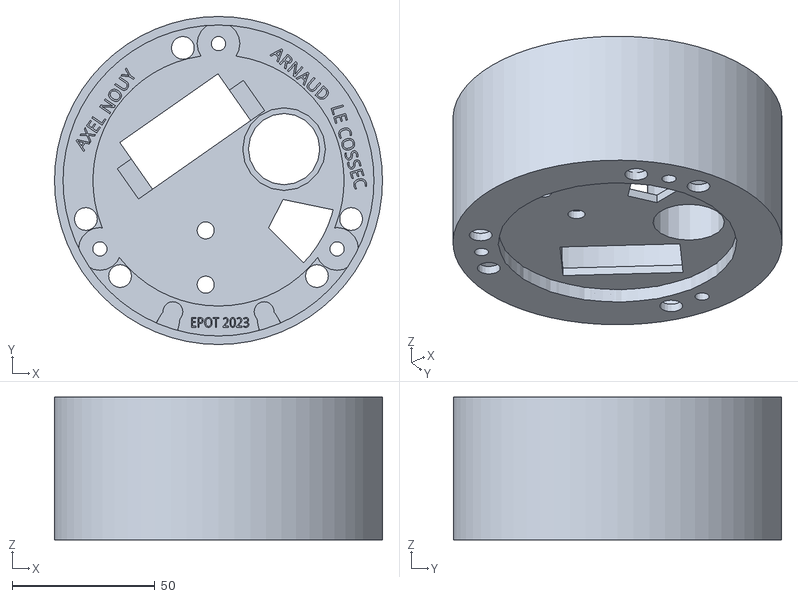
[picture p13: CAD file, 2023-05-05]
Mechanique/EPOT_TANK_TOP_v2.stl
115.0 x 115.0 x 50.0

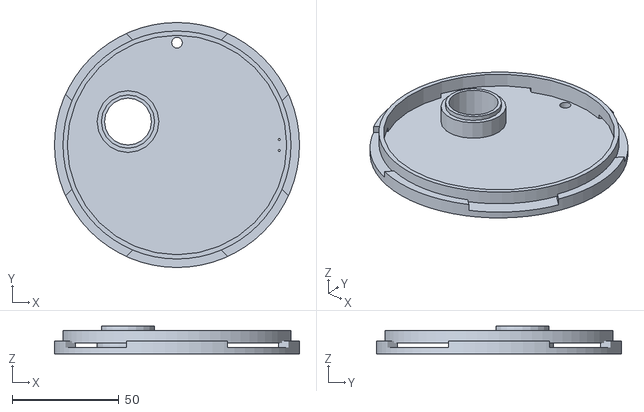
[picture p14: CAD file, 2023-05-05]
Mechanique/EPOT_TOP_COVER.stl
115.0 x 115.0 x 13.0

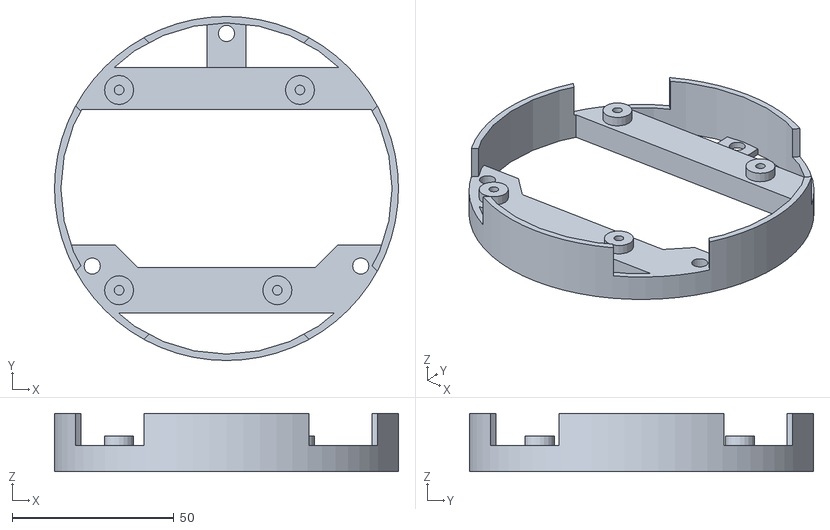
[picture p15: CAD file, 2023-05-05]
Mechanique/EPOT_CMD_SUPPORT.stl
106.5 x 106.5 x 18.0

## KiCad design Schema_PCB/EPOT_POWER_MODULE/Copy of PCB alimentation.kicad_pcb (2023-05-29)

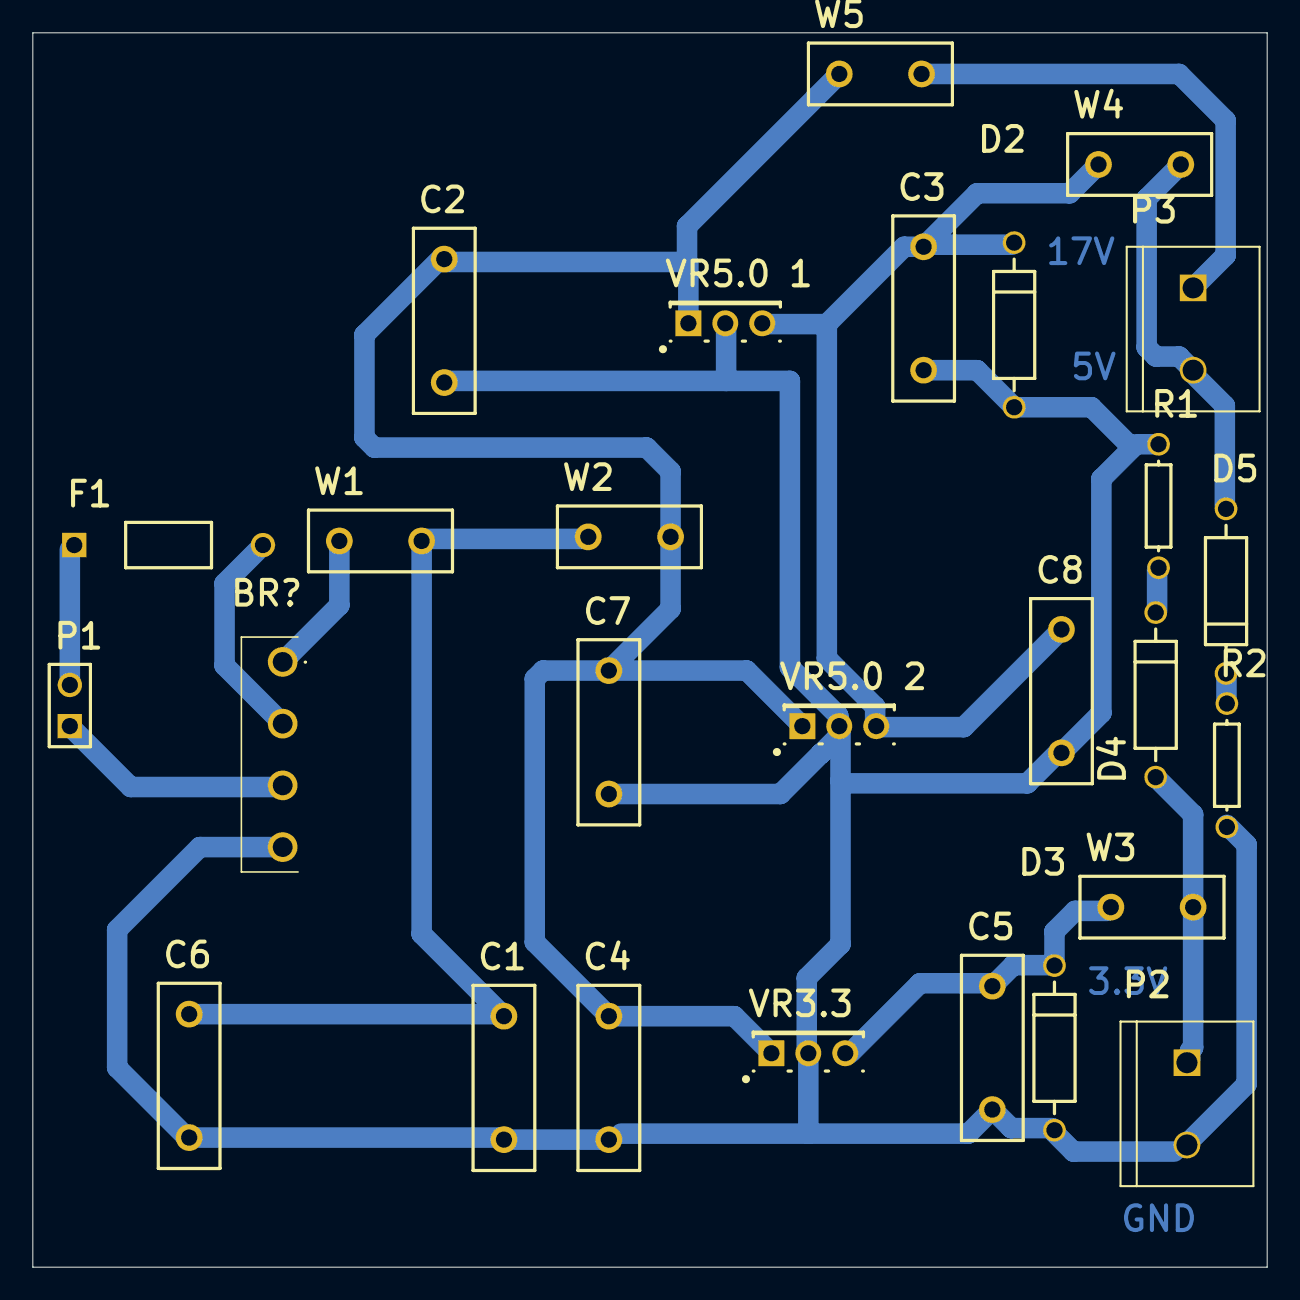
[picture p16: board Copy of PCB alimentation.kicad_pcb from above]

Board: 2 copper layers, 76.2 x 76.2 mm, 27 parts (0 on the bottom side), 14 nets.

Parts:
BR?: KBP206G
C1, C2, C3, C4, C5, C6, C7, C8: Cap; RAD-0.3
D2, D3: D Zener; DIODE-0.4
D4, D5: Diode; DIODE-0.4
F1: Fuse 1; PIN-W2/E2.8
P1: Header in; HDR1X2
P2: Header out; TE_282837-2
P3: 282837-2; TE_282837-2
R1, R2: Res1; AXIAL-0.3
VR3.3, VR5.0 1, VR5.0 2: Volt Reg; 369-03
W1, W2, W3, W4, W5: Jumper; RAD-0.2

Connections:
GND: BR?.4, C1.1, C2.1, C3.1, C4.1, C5.1, C6.1, C7.1, C8.1, D2.1, D3.1, P2.2, R1.1, R2.1, VR3.3.2, VR5.0 1.2, VR5.0 2.2
NetBR?_1: BR?.1, W1.1
NetBR?_2: BR?.2, F1.2
NetBR?_3: BR?.3, P1.1
NetC1_2: C1.2, C6.2, W1.2, W2.1
NetC2_2: C2.2, C4.2, C7.2, VR3.3.1, VR5.0 1.1, VR5.0 2.1, W2.2, W5.1
NetC3_2: C3.2, C8.2, D2.2, VR5.0 1.3, VR5.0 2.3, W4.1
NetC5_2: C5.2, D3.2, VR3.3.3, W3.1
NetD4_1: D4.1, P2.1, W3.2
NetD4_2: D4.2, R1.2
NetD5_1: D5.1, P3.2, W4.2
NetD5_2: D5.2, R2.2
NetF1_1: F1.1, P1.2
NetP3_1: P3.1, W5.2

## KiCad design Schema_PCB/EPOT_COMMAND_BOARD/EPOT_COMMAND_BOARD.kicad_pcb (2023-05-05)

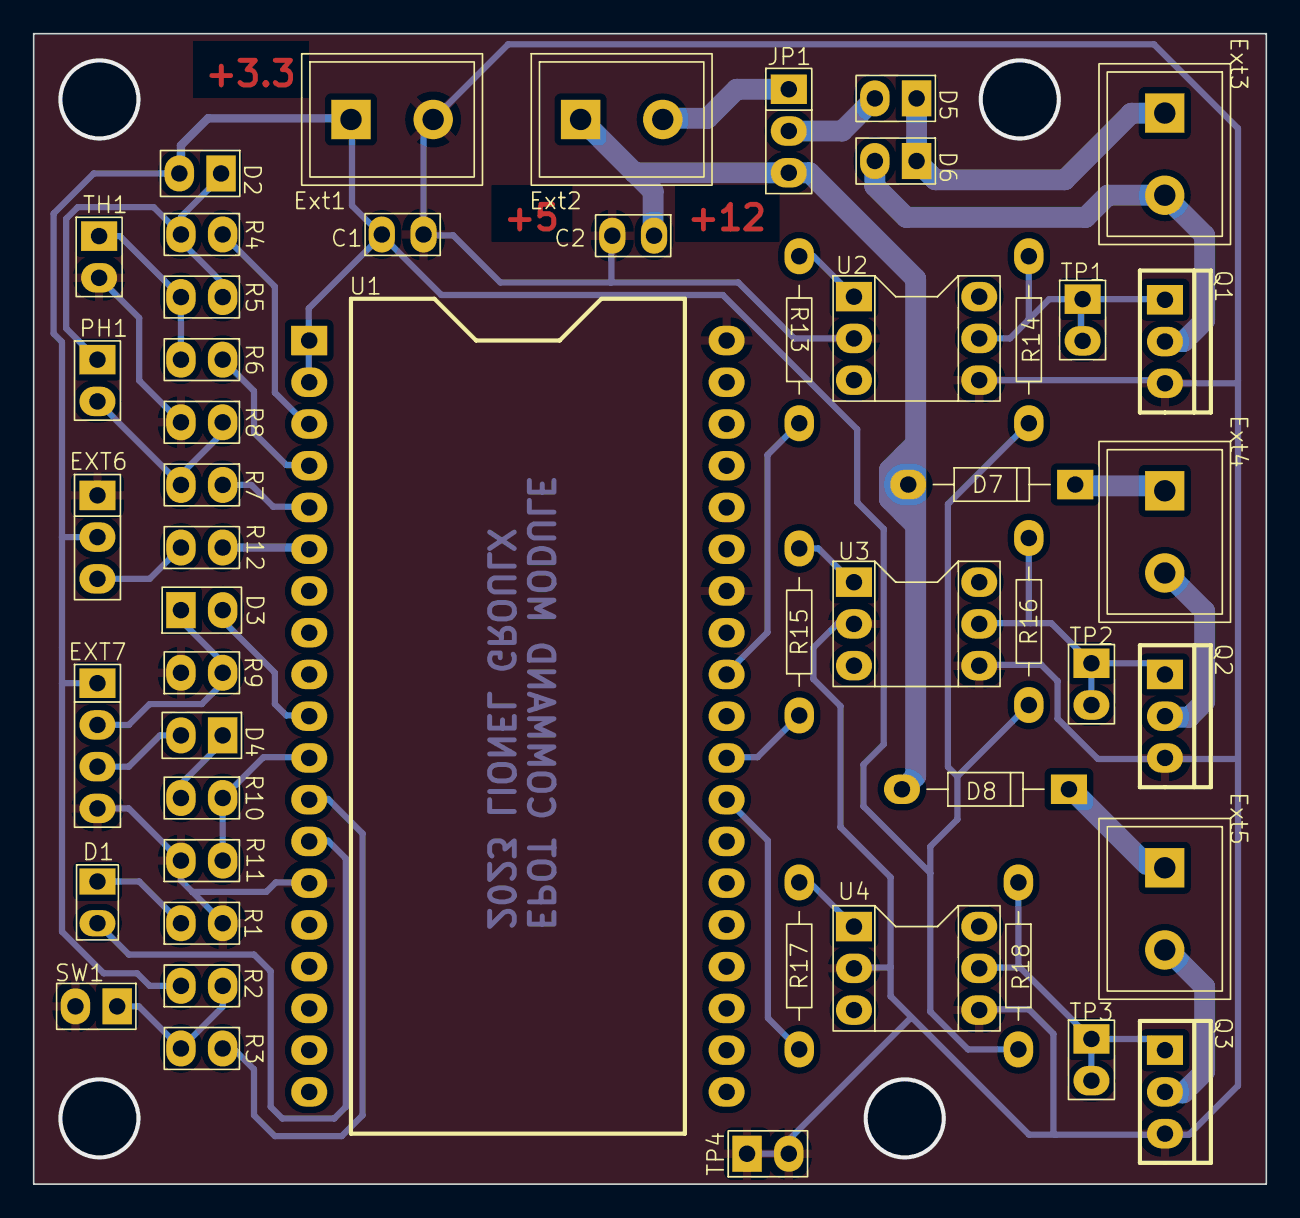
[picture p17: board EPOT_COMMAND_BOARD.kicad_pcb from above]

Board: 2 copper layers, 75.0 x 70.0 mm, 50 parts (0 on the bottom side), 37 nets.

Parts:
C1, C2: 0.1uF; Unpolarized_capacitor
D1: LED; LED_2.54
D2, D3, D4, D5, D6: 1N4004; Header_2P_2.54
D7, D8: 1N4004; Diode_10.16p
EXT6: Humidity sensor; Header_3P_2.54
EXT7: Ultrasonic_Sensor_HC-SR04; Header_4P_2.54
Ext1, Ext2, Ext3, Ext4, Ext5: TERMINAL BLOCK 2PINS
JP1: Jumper_3_Open; Header_3P_2.54
PH1: R_Photo; Header_2P_2.54
Q1, Q2, Q3: NMOS; TO220
R1, R2, R5, R8: 1k; Vertical_resistor_2.54
R3, R4, R6, R7, R12: 100; Vertical_resistor_2.54
R9, R11: 10k; Vertical_resistor_2.54
R10: 3.7k; Vertical_resistor_2.54
R13, R15, R17: 200; Resistor_10.16p
R14, R16, R18: 10k; Resistor_10.16p
SW1: SW_MEC_5G; Header_2P_2.54
TH1: Thermistor_NTC; Header_2P_2.54
TP1, TP2, TP3, TP4: Header_2P_2.54
U1: ESP32_38P
U2, U3, U4: 4N25; DIP_6_2.54p_7.62w

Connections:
+3.3V: C1.1, D2.2 (A), EXT6.2 (Vcc), EXT7.1 (Vcc), Ext1.1, R2.1, R14.2, R16.2, R18.2, U1.1 (3V3), U1.2 (EN)
+5V: C2.1, D7.2 (A), D8.2 (A), Ext2.1, JP1.3 (B)
+12V: Ext2.2, JP1.1 (A)
/ADC_Top_Ref: R4.1, U1.3 (IO36/A0)
/Humidity_Sensor_Out: R12.2, U1.6 (IO35/A7)
/LED_Control: R15.1, U1.28 (IO17)
/Photo_Out: R7.1, U1.5 (IO34/A6)
/Pump_Control: R13.1, U1.30 (IO18)
/Status_LED: D1.2 (A), U1.13 (IO12/A15)
/Sync_Button: R3.1, U1.12 (IO14/A16)
/Thermistor_Out: R6.1, U1.4 (IO39/A3)
/UV_Control: R17.1, U1.27 (IO16)
/Ultrasonic_Sensor_Echo: R10.1, R11.2, U1.11 (IO27/A17)
/Ultrasonic_Sensor_Trig: D3.2 (A), U1.10 (IO26/A19)
GND: C1.2, C2.2, EXT6.1 (GND), EXT7.4 (GND), Ext1.2, Q1.3 (S), Q2.3 (S), Q3.3 (S), R1.2, R8.2, R9.1, R11.1, SW1.2 (A), TH1.2, TP4.1, TP4.2, U1.14 (GND), U1.32 (GND), U1.38 (GND), U2.2, U2.4, U3.2, U3.4, U4.2, U4.4
unnamed: D1.1 (K), R1.1
unnamed: D2.1 (K), PH1.1, R4.2, R5.1
unnamed: D3.1 (K), EXT7.2 (Trig), R9.2
unnamed: D4.2 (A), EXT7.3 (Echo)
unnamed: D4.1 (K), R10.2
unnamed: D5.2 (A), JP1.2 (C)
unnamed: D5.1 (K), D6.1 (K), Ext3.1
unnamed: D6.2 (A), Ext3.2, Q1.2 (D)
unnamed: D7.1 (K), Ext4.1
unnamed: D8.1 (K), Ext5.1
unnamed: EXT6.3 (Aout), R12.1
unnamed: PH1.2, R7.2, R8.1
unnamed: Q1.1 (G), R14.1, TP1.1, TP1.2, U2.5
unnamed: Ext4.2, Q2.2 (D)
unnamed: Q2.1 (G), R16.1, TP2.1, TP2.2, U3.5
unnamed: Ext5.2, Q3.2 (D)
unnamed: Q3.1 (G), R18.1, TP3.1, TP3.2, U4.5
unnamed: R2.2, R3.2, SW1.1 (A)
unnamed: R5.2, R6.2, TH1.1
unnamed: R13.2, U2.1
unnamed: R15.2, U3.1
unnamed: R17.2, U4.1

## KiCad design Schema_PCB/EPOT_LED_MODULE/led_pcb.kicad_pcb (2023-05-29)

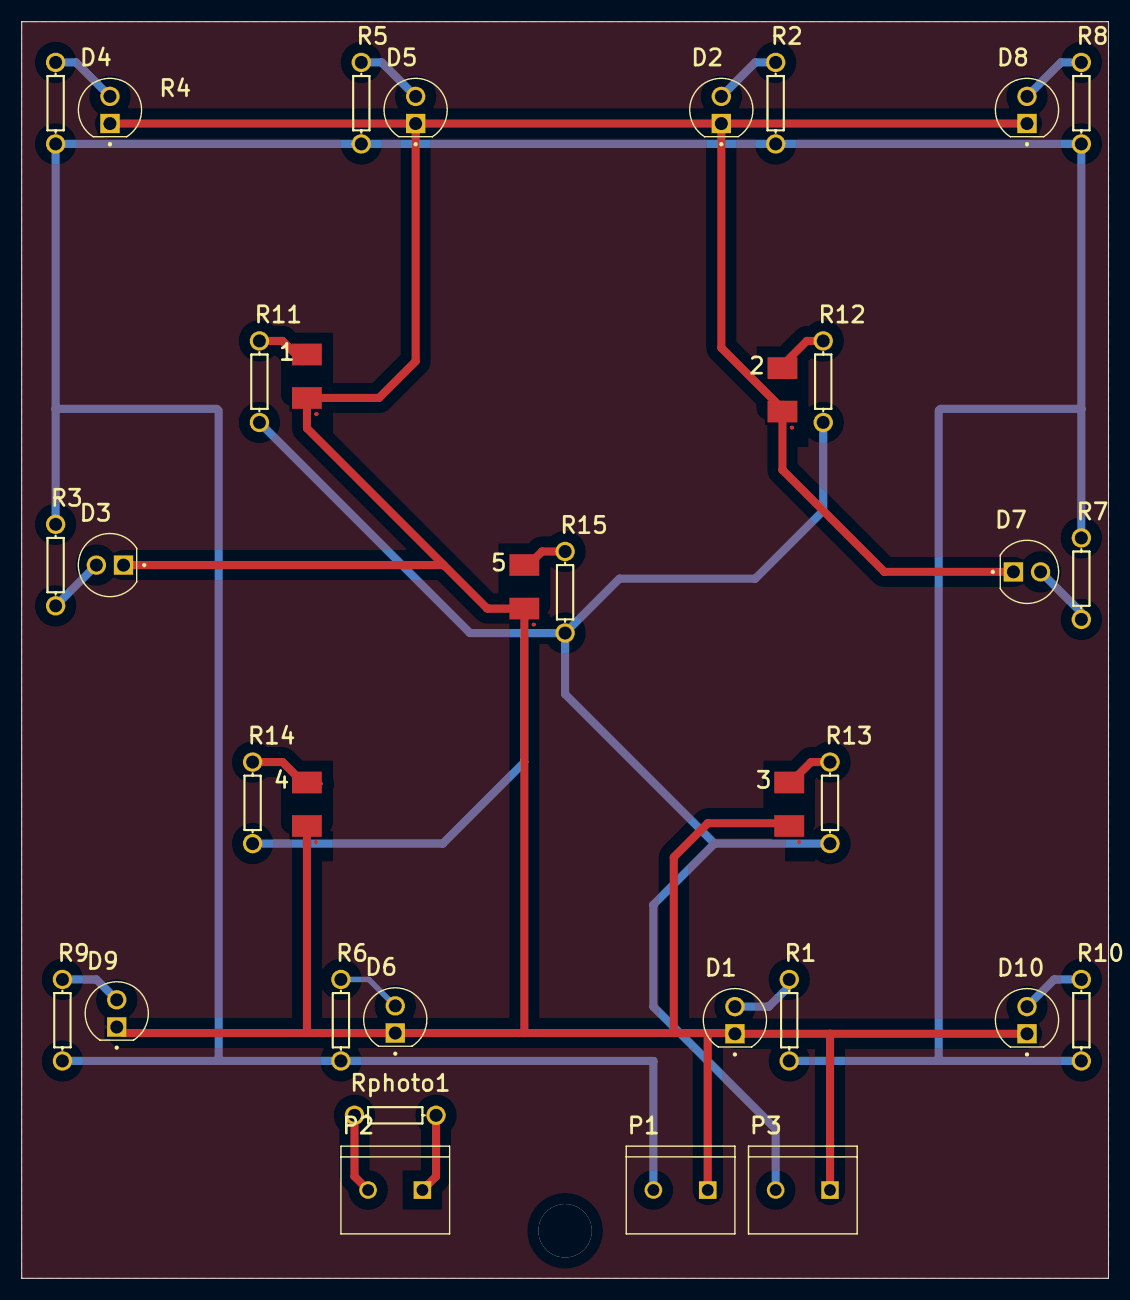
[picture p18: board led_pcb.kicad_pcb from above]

Board: 2 copper layers, 101.6 x 117.5 mm, 34 parts (0 on the bottom side), 15 nets.

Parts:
1: uv del 1; PCBComponent_1
2: uv del 2; PCBComponent_1
3: uv del 3; PCBComponent_1
4: uv del 4; PCBComponent_1
5: uv del 5; PCBComponent_1
D1, D2, D3, D4, D5, D6, D7, D8, D9, D10: L08R5000Q1; LEDRD254W57D500H1070
P1, P2, P3: 282837-2; TE_282837-2
R1, R2, R3, R4, R5, R6, R7, R8, R9, R10, R11, R12, R13, R14, R15: Res1; AXIAL-0.3
Rphoto1: Res1; AXIAL-0.3

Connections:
GND: 1.1, 2.1, 3.1, 4.1, 5.1, D1.C, D2.C, D3.C, D4.C, D5.C, D6.C, D7.C, D8.C, D9.C, D10.C, P1.1, P3.1
NetD1_A: D1.A, R1.1
NetD2_A: D2.A, R2.1
NetD3_A: D3.A, R3.1
NetD4_A: D4.A, R4.1
NetD5_A: D5.A, R5.1
NetD6_A: D6.A, R6.1
NetD7_A: D7.A, R7.1
NetD8_A: D8.A, R8.1
NetD9_A: D9.A, R9.1
NetD10_A: D10.A, R10.1
NetP1_2: P1.2, R1.2, R2.2, R3.2, R4.2, R5.2, R6.2, R7.2, R8.2, R9.2, R10.2
NetP2_1: P2.1, Rphoto1.2
NetP2_2: P2.2, Rphoto1.1
NetP3_2: P3.2, R11.2, R12.2, R13.2, R14.2, R15.2

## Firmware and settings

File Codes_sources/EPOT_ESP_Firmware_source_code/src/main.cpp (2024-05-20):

/*****************************************************
EPOT Project - ESP32 Firmware
(c)2023 Arnaud LE COSSEC
(c)2023 College Lionel Groulx
*****************************************************/

/*****************************************************
Change Notes : 
28/03/2023a : File creation
              void LED_init(void);
              void LED_set(uint8_t freq);
              void Ultrasonic_init(void);
              float Ultrasonic_Read(void);
              void Aref_init(void);
              void Temp_init(void);
              float Temp_Read(void);
              void Photo_Cell_init(void);
              float Photo_Cell_Read(void);
              void Humidity_init(void);
              float Humidity_Read(void);
29/03/2023a : POST test implementation
              LED not flashing bug fixed (prototype used instead of function call)
29/03/2023b : Task implementation
              Task Sensors Update
              Task Sensors Print - debug only, to be removed later on
29/03/2023c : Wifi setup implementation
29/03/2023d : Database setup implementation
              Code separation with EPOT_lib.h
31/03/2023a : watchdog implementation
03/04/2023a : Sensors to database
              Ledc library error fixed
04/04/2023a : Error log to database
              void Database_Self_test_repport(uint8_t Error_Count, uint8_t *Error_log)
              Change uint8_t Self_test(uint8_t *Error_log_table) : text as const char*
04/04/2023b : Bluetooth implementation
12/04/2023a : Startup sequence (stopped due to flash size issue)
13/04/2023a : New partion table with 3MB free for application use
13/04/2023b : Startup sequence (continuation)
              Task_database_read() / Task_database_write() deleted because replaced by task_database_update()
19/04/2023a : Database authentification refresh implementation
              [bug fix] "Invalid data; couldn't parse JSON object, array, or value." fixed : when left unconnected, 
              thermistor value was too large for the database. Temperature capped to 70°C
19/04/2023b : [bug fix] Bluetooth authentification systematic timeout fixed
20/04/2023a : [bug fix] Bluetooth authentification failed when retry
20/04/2023b : SSID and WIFI password exchange
27/04/2023a : Wifi connects from exchanged SSID and Password
27/04/2023b : Queue recieve moved to read sensors more often Task_Database_Update_routine
              Wifi connection timeout : if ESP can't connect to wifi, it restart credidentials exchange via Bluetooth
03/05/2023a : Permanent storage implementation with preferences.h library
              Push button reading implementation
03/05/2023b : Repace sensor queues for global variables to facilitate access for multiple tasks
03/05/2023c : Database commands and threshold levels reading
04/05/2023a : Automation - Force run/stop
              LED GPIO 17 and UV GPIO16 are not connected on VROVER-E. Replaced for GPIO 5 and 15 respectively
08/05/2023a : Database triggers
09/05/2023a : Update commands and levels from database triggers
09/05/2023b : Automation - Auto mode
10/05/2023a : Database sensor update only when sensor value changed
              if button pressed durring operation, hard reset is performed
15/05/2023a : RTOS Removed. RTOS handles memory in a weird way : random crashes due to memory allocation errors. 
15/05/2023b : Database update at startup
18/05/2023a : [BUG FIX] after 1h of runtime, firebase wants to refresh authentification tokens, but fails due to lack of memory
19/05/2023a : Delay added after firebase stream reconnection. Watchdog timeout extended to accomodate this delay.
20/05/2023a : LED to show CPU activity in the loop
22/05/2023a : Added relay output to cut 5v at startup
              Ultrasonic sensor measure overhaul
23/05/2023a : Pump automation overhaul
28/05/2023a : Commenting

                           

*****************************************************/


/*****************************************************
Preprocessors
*****************************************************/
#include <esp_task_wdt.h>
#include <esp_bt.h>
#include <esp_bt_main.h>
#include <Preferences.h>
#include <WiFi.h>
#include <BluetoothSerial.h>
#include <math.h>
#include <Firebase_ESP_Client.h>
#include "addons/TokenHelper.h"
#include "addons/RTDBHelper.h"
#include "EPOT_lib.h"

/*****************************************************
Prototypes
*****************************************************/



/*****************************************************
Global variables
*****************************************************/

char g_ssid[80] = {};
char g_password[80] = {};

float last_temperature = 0.0;
int last_light_level = 0;
float last_humidity_percentage = 0.0;
int last_water_level_percentage = 0;
int water_level_percentage_test_a = 0;
int water_level_percentage_test_b = 0;
uint water_level_test_phase = 0;

int last_light_manual_intensity = 100;
int last_UV_manual_intensity = 100;
bool last_pump_state = STATE_OFF;

int current_time, last_time, last_watering, last_ultrasonic_update = millis();



/*****************************************************
Main
*****************************************************/

void setup() {
  heap_caps_free(NULL);

  
  // ------------------ Serial Setup for debug ------------------
  Serial.begin(9600);

  Serial.println("--------- EPOT PROJET DEBUG OUTPUT --------");
  Serial.println("Firmware 28/05/23a (c)2023 Arnaud LE COSSEC");

  Serial.println(heap_caps_get_free_size(MALLOC_CAP_8BIT));

  // ------------------ Pin Setup ------------------

  pinMode(LED_CONTROL_PIN, OUTPUT);
  digitalWrite(LED_CONTROL_PIN, HIGH);
  pinMode(UV_CONTROL_PIN, OUTPUT);
  digitalWrite(UV_CONTROL_PIN, HIGH);
  pinMode(PUMP_CONTROL_PIN, OUTPUT);
  digitalWrite(PUMP_CONTROL_PIN, HIGH);

  pinMode(POWER_RELAY, OUTPUT);
  digitalWrite(POWER_RELAY, LOW);

  LED_init();
  Ultrasonic_init();
  Aref_init();
  Temp_init();
  Photo_Cell_init();
  Humidity_init();

  // ---------------- visual check ------------------
  delay(1000);

  LED_set(1); // Set LED to 1Hz during startup to indicate CPU activity

  uint8_t Error_log[11] = {};
  uint8_t Error_Count = Self_test(Error_log);
  if(Error_Count>0){LED_set(10);} // Set LED to 10Hz if error occured

  // ---------------- Startup procedure -------------

  bool has_credidentials_stored;

  // init storage for wifi credidentials
  Storage_init();           

  // Check for wifi credidentials in storage
  if(Storage_read(g_ssid, g_password)==FAIL || Button_read()==PRESSED){
    has_credidentials_stored = false;
    Serial.println("No credidentials saved");
  }
  else{
    Serial.println("credidentials found in memory");
    has_credidentials_stored = true;
    Serial.println(g_ssid);
    Serial.println(g_password);
  }

  // if ssid and password are not stored in memory, then proceed to initial configuration
  l_initial_configuration: // label
  if(has_credidentials_stored==false){    
    Serial.println("Initial configuration ...");
    // -- initialize Bluetooth and wait for connexion --
    Bluetooth_Setup();

    // -- Wait for hello signal from application --
    const char* Msg_Ref = "HELLO_EPOT_APP_0";
    char Msg[20] = {};
    if(Bluetooth_Receive_String(Msg, 20, BLUETOOTH_TIMEOUT)){
      Serial.println("[ERR] Hello timeout, disconnecting...");   // Fail condition
      Bluetooth.disconnect();
      goto l_initial_configuration;
    }
    if(compare_tables(Msg_Ref, Msg, 16)){
      Serial.println("[ERR] Hello mismatch, disconnecting...");   // Fail condition
      Bluetooth.disconnect();
      goto l_initial_configuration;
    }
 
    // -- Send hello signal for application --
    //Bluetooth.println("HELLO_EPOT_CMD_0");

    delay(100);

    // -- Exchange data

    Bluetooth.write(1);                                                 // indicate to the app an SSID request
    if(Bluetooth_Receive_String(g_ssid, 80)){
      Serial.println("[ERR] SSID request timeout, disconnecting...");   // Fail condition
      Bluetooth.disconnect();
      goto l_initial_configuration;
    }

    Serial.println(g_ssid);

    Bluetooth.write(2);                                                 // indicate to the app an password request
    if(Bluetooth_Receive_String(g_password, 80)){
      Serial.println("[ERR] Password request timeout, disconnecting...");   // Fail condition
      Bluetooth.disconnect();
      goto l_initial_configuration;
    }
  
    Serial.println(g_password);

    Bluetooth.write(3);                                                 // indicate to the app the end of configuration

    Bluetooth.disconnect();
    
  }

  Bluetooth.end();

  esp_bluedroid_disable();                                              // Deactivate and release Bluetooth memory to save RAM
  esp_bluedroid_deinit();
  esp_bt_controller_disable();
  esp_bt_controller_deinit();
  esp_bt_mem_release(ESP_BT_MODE_BTDM);

  // ------------------ Setup wifi ------------------

  if(Wifi_Setup(g_ssid, g_password, WIFI_TIMEOUT)){
    Serial.println("[ERR] Wifi timeout, restarting credidentials exchange via Bluetooth...");   // Fail condition
    WiFi.disconnect();
    has_credidentials_stored = false;
    goto l_initial_configuration;                                                               // Credidentials may be wrong, go to initial configuration
  }

  // if credidentials weren't saved and wifi connection is successful, then save credidentials
  if(has_credidentials_stored == false){
    Serial.println("New credidentials saved");
    Storage_write(g_ssid, g_password);
  }

  // terminate storage instance
  Storage_close();

  // ---------------- ENABLE 5v ----------------

  delay(1000);
  digitalWrite(POWER_RELAY, HIGH);          // enable +5v rail for LEDs and ultrasonic sensors
  delay(1000);


  // ---------------- Setup database ----------------

  Database_init();                          // Initialize database connexion
  // Write test
  Database_Write_int("/EPOT1/STATUS", 1);   // indicate to the app that the ESP has access to the database

  Database_Self_test_repport(Error_Count, Error_log);   // Repport errors to the database

  //delay(500);

  Database_trigger_init();

  delay(6000);

  // -------------- Read initial values ----------------

  Database_Read_float("/EPOT1/CMD/1_CMD_Humidity_threshold", &g_humidity_threshold);
  Database_Read_bool("/EPOT1/CMD/2_CMD_Pump_manual_on_off", &g_pump_manual_on_off);
  Database_Read_int("/EPOT1/CMD/3_CMD_Pump_auto_on_time", &g_pump_auto_on_time);
  Database_Read_bool("/EPOT1/CMD/4_CMD_Watering_manual_auto", &g_watering_manual_auto);
  
  Database_Read_int("/EPOT1/CMD/5_CMD_Light_threshold", &g_light_threshold);
  Database_Read_int("/EPOT1/CMD/6_CMD_Light_manual_intensity", &g_light_manual_intensity);
  Database_Read_bool("/EPOT1/CMD/7_CMD_Light_manual_auto", &g_light_manual_auto);
  
  Database_Read_int("/EPOT1/CMD/8_CMD_UV_threshold", &g_UV_threshold);
  Database_Read_int("/EPOT1/CMD/9_CMD_UV_manual_intensity", &g_UV_manual_intensity);
  Database_Read_bool("/EPOT1/CMD/a_CMD_UV_manual_auto", &g_UV_manual_auto);

  // ---------------- Setup Watchdog ----------------

  esp_task_wdt_init(WDT_TIMEOUT, true);
  esp_task_wdt_add(NULL);

  // ---------------- Status LED --------------------

  ledcDetachPin(LED_PIN);   // From now on, the status LED will be driven manualy

}

void loop() {
  esp_task_wdt_reset();   // reset watchdog timer

  digitalWrite(LED_PIN, !digitalRead(LED_PIN)); // Flip LED state : if the CPU crashes, the LED stops

  current_time = millis(); // update current time for time-based tasks

  if(!Firebase.ready()){    // Firebase.ready() updates the database authentification tokens
    digitalWrite(LED_PIN, LOW);
  }

  // Old token refresh method : uses too much memory
  //if (Firebase.isTokenExpired()){
  //  Firebase.refreshToken(&Database_config);
  //  Serial.println("Refresh token");
  //}

  if(StreamCallBackTimeout_status == true){ // If the database stream callback fails, terminate it and create a new one
    Firebase.RTDB.endStream(&Database_stream);
    Firebase.RTDB.removeStreamCallback(&Database_stream);
    Database_trigger_init();
    delay(6000);
    StreamCallBackTimeout_status = false;
  }

  if(Button_read()==PRESSED){               // reset ESP if the button is pressed. Note for the future : put this into an interrupt
    ESP.restart();
  }

  
  /*****************************************************
  SENSOR UPDATE
  *****************************************************/

  // Read temperature
  float raw_temperature = Temp_Read();
  if(raw_temperature > 70.0){raw_temperature = 70.0;}     // Cap temperature to 70° to prevent inf value to try to access to the database
  g_temperature=round(raw_temperature*10)/10;             // allow 0.1 resolution

  // Read light level
  float raw_light_level = Photo_Cell_Read();               // Photo resistor is not a precise lux meter, use stages instead
  if(raw_light_level > 600000){raw_light_level = 0;}       // Dim hallway
  else if(raw_light_level > 70000){raw_light_level = 20;}  // Moonlit night
  else if(raw_light_level > 10000){raw_light_level = 40;}  // Dark room
  else if(raw_light_level > 1500){raw_light_level = 60;}   // Dark overcast day / Bright room
  else if(raw_light_level > 300){raw_light_level = 80;}    // Overcast day
  else {raw_light_level = 100;}                            // Full day light
  g_light_level = raw_light_level;
  
  // Read Humidity level
  g_humidity_percentage = round(Humidity_Read());
  
  // Read water level level
  // We wait 10s between each measures to avoid ultrasonic bouncing in the reservoir messing up with the sensor
  // We still face inconsistencies between measures, so we take two samples, and if they are identical, they are probably correct
  if(current_time - last_ultrasonic_update > 10000){      
    if(water_level_test_phase == 0){                      
      water_level_percentage_test_a = round(Ultrasonic_Read());
      //Serial.print("p1 ");
      //Serial.println(water_level_percentage_test_a);
      water_level_test_phase = 1;
      last_ultrasonic_update = current_time;
    }
    else if(water_level_test_phase == 1){
      water_level_percentage_test_b = round(Ultrasonic_Read());
      //Serial.print("p2 ");
      //Serial.println(water_level_percentage_test_b);
      if(water_level_percentage_test_a == water_level_percentage_test_b){
        float result = ((WATER_TANK_HEIGHT+WATER_TANK_SENSOR_SEPERATION)-water_level_percentage_test_a);
        g_water_level_percentage = round((result/WATER_TANK_HEIGHT)*100); // accuracy is not needed for the tank level
        Serial.println(g_water_level_percentage);
      }
      water_level_test_phase = 0;
      last_ultrasonic_update = current_time;
    }
  }

  /*****************************************************
  DATABASE UPDATE
  *****************************************************/

  if(current_time - last_time > 5000){      // Sensor values are sent to the database every 5s to save bandwidth
     
    // Update database
    if(g_temperature != last_temperature){  // Sensor are only updated of they are different that the previous measure
      Database_Write_float("EPOT1/SENSOR_Temperature", g_temperature);
      last_temperature = g_temperature;
    }
    if(g_light_level != last_light_level){  // Sensor are only updated of they are different that the previous measure
      Database_Write_int("EPOT1/SENSOR_Light", g_light_level);
      last_light_level = g_light_level;
    }
    if(g_humidity_percentage != last_humidity_percentage){  // Sensor are only updated of they are different that the previous measure
      Database_Write_float("EPOT1/SENSOR_Humidity", g_humidity_percentage);
      last_humidity_percentage = g_humidity_percentage;
    }
    if(g_water_level_percentage != last_water_level_percentage){  // Sensor are only updated of they are different that the previous measure
      Database_Write_int("EPOT1/SENSOR_Water_level", g_water_level_percentage);
      last_water_level_percentage = g_water_level_percentage;
    }
    
    Serial.println("Database Sensor Updated");
    
    last_time = current_time;

  }
  /*****************************************************
  LIGHT AUTOMATION
  *****************************************************/

  if(g_light_manual_auto == MANUAL){    
    // Manual mode
    if(g_light_manual_intensity != last_light_manual_intensity){
      analogWrite(LED_CONTROL_PIN, (255-g_light_manual_intensity*2.5));
      last_light_manual_intensity = g_light_manual_intensity;
    }
  }
  else{
    // Auto mode
    if(g_light_level <= g_light_threshold){ 
      analogWrite(LED_CONTROL_PIN, (255-g_light_manual_intensity*2.5));
    }
    else{
      analogWrite(LED_CONTROL_PIN, 255);
    }
  }

  /*****************************************************
  UV AUTOMATION
  *****************************************************/

  if(g_light_manual_auto == MANUAL){ //if(g_UV_manual_auto == MANUAL){ -> UV manual mode is now tied the normal LED manual mode
    // Manual mode
    if(g_UV_manual_intensity != last_UV_manual_intensity){
      analogWrite(UV_CONTROL_PIN, (255-g_UV_manual_intensity*2.5));
      last_UV_manual_intensity = g_UV_manual_intensity;
    }
  }
  else{
    // Auto mode
    if(g_light_level <= g_UV_threshold){
      analogWrite(UV_CONTROL_PIN, (255-g_UV_manual_intensity*2.5));
    }
    else{
      analogWrite(UV_CONTROL_PIN, 255);
    }
  }

  /*****************************************************
  WATERING AUTOMATION
  *****************************************************/

  if(g_watering_manual_auto == MANUAL){
    // Wattering manual mode
    digitalWrite(PUMP_CONTROL_PIN, !g_pump_manual_on_off); 
  }else
  {
    //Wattering auto mode : if current soil humidity is below the set threshold, 
    //then the pump is activated for 5s every minute to let the soil absorb the water
    if(g_humidity_percentage < g_humidity_threshold){
      if((current_time - last_watering > 60000) && (last_pump_state == STATE_OFF) && (g_water_level_percentage > 5)){
        digitalWrite(PUMP_CONTROL_PIN, STATE_ON);
        last_pump_state = STATE_ON;
        last_watering = current_time;
        Serial.println("ON");
      }
      else if((current_time - last_watering > g_pump_auto_on_time) && (last_pump_state == STATE_ON)){
        digitalWrite(PUMP_CONTROL_PIN, STATE_OFF);
        last_pump_state = STATE_OFF;
        last_watering = current_time;
        Serial.println("OFF");
      }
    }
    else{
      digitalWrite(PUMP_CONTROL_PIN, STATE_OFF);
      last_pump_state = STATE_OFF;
      Serial.println("F OFF");
    }
  }    

}
